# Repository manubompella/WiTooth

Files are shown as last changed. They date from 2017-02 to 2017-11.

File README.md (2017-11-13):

# WiTooth

The WiTooth is based on Espressif ESP32 WiFi-BT-BLE SoC (System on Chip), ESP32 contains two low-power Xtensa® 32-bit LX6 microprocessors running at 80 MHz. Features include:

 * Integrated 802.11 BGN WiFi transceiver
 * Integrated dual-mode Bluetooth (classic and BLE)
 * Dual-core Tensilica LX6 microprocessor
 * Up to 240MHz clock frequency
 * 520kB internal SRAM
 * 10-electrode capacitive touch support
 * Hardware accelerated encryption (AES, SHA2, ECC, RSA-4096)
 * 2.2 to 3.6V operating range
 * 2.5 µA deep sleep current
 * 3 SPI, 2 I2C, 2 UART
 * 16 PWM outputs
 * 2 DAC
 * 2 I2S
 * 18 analog-to-digital converter (ADC) channels
 
## Platform Features

 * Compatible with Arduino IDE
 * USB powered
 * CP2102 USB-to-UART Bridge
 * Extended breadboard compatible headers
 * UART, SPI, I2C
 * On-board RESET
 
## Maintainers

The WiTooth is maintained by thingTronics Innovations.

Main contributor:
 * Manohar Bompella@<manohar.bompella@thingtronics.com>
 * Poornima Nagesh @<poornima.nagesh@thingtronics.com>
 * Lovelesh Patel @<lovelesh.patel@thingtronics.com>

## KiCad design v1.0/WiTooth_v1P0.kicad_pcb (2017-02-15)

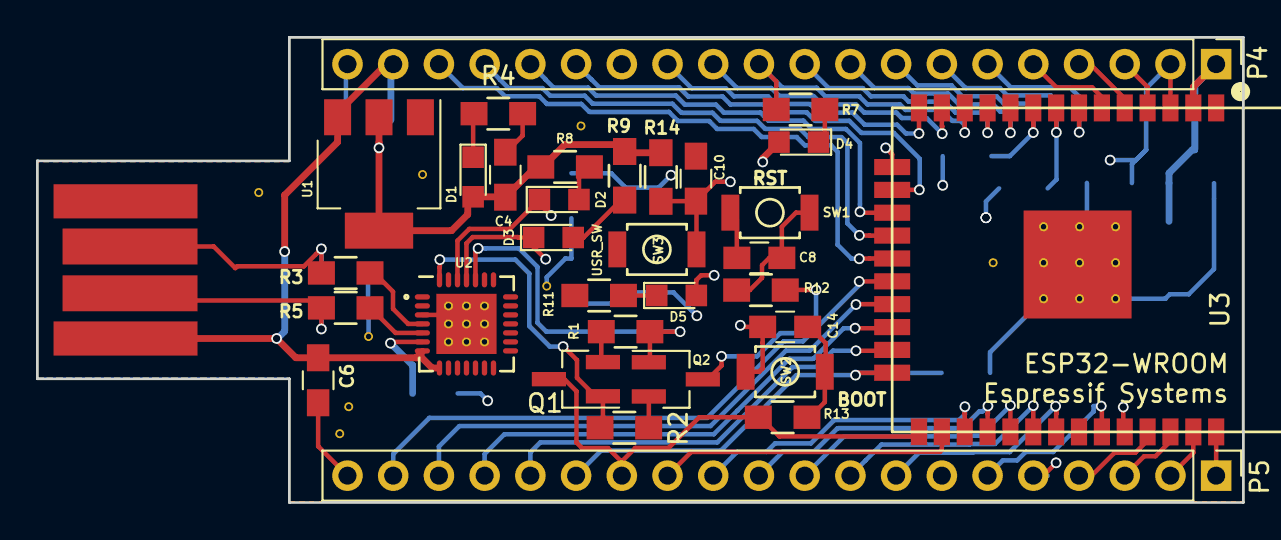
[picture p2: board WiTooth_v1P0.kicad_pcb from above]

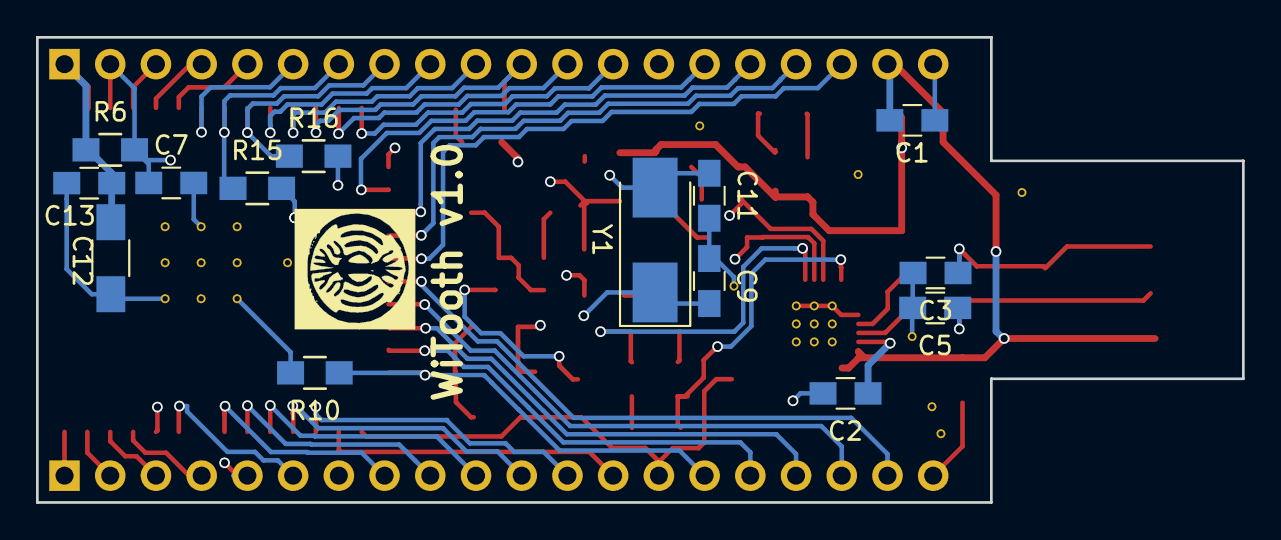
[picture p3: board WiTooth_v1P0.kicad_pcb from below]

Board: 4 copper layers, 67.0 x 25.8 mm, 47 parts (14 on the bottom side), 54 nets.

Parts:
C1, C4: 10uF; C_0805_HandSoldering
C2: 0.1uF; C_0805_HandSoldering
C3, C5: 47pF; C_0805_HandSoldering
C6, C13: 1uF; C_0805_HandSoldering
C7, C8, C10, C14: 1nF; C_0805_HandSoldering
C9, C11: 27pF; C_0805_HandSoldering
C12: 100uF; C_1206_HandSoldering
D1: PWR_GREEN; LED_0805
D2, D3: YELLOW; LED_0805
D4: CONN_LED; LED_0805
D5: USER_LED; LED_0805
P1: USB_A_MALE; usb-PCB_male
P4, P5: CONN_01X20; Pin_Header_Straight_1x20_Pitch2.54mm
Q1, Q2: Q_NPN_EBC; SOT-23_Handsoldering
R1, R2, R6: 12K; R_0805_HandSoldering
R3, R5: 27E; R_0805_HandSoldering
R4: 1K; R_0805_HandSoldering
R7, R11, R12, R13, R14: 470E; R_0805_HandSoldering
R8, R9: R; R_0805_HandSoldering
R10: 5K; R_0805_HandSoldering
R15, R16: 0E; R_0805_HandSoldering
SW1: RESET; SW_SPST_B3U-1000P_SUNROM
SW2: BOOT; SW_SPST_B3U-1000P_SUNROM
SW3: USER_SW; SW_SPST_B3U-1000P_SUNROM
U1: AMS1117-3V3; SOT-223
U2: CP2102; QFN-28-1EP_5x5mm_Pitch0.5mm
U3: ESP-32_WROOM32_Rectangle; ESP32-WROOM_SMALLER_FOOTPRINT
Y1: Crystal; Crystal_SMD_0603-2pin_6.0x3.5mm_HandSoldering

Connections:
+3V3: C4.1, C12.1, C13.1, D1.2, D4.2, P4.1, R6.1, R8.1, R9.1, R14.1, U1.2, U1.4, U3.2
+5V: C1.1, C6.1, P1.1, P4.19, U1.3, U2.7, U2.8
CLK: P5.19, U3.20
CMD: P4.18, U3.19
DTR: Q1.1, R2.2, U2.28
EN: C7.1, P4.2, Q2.3, R6.2, R12.1, U3.3
GND: C1.2, C2.2, C3.2, C4.2, C5.2, C6.2, C7.2, C8.2, C9.2, C10.2, C11.2, C12.2, C13.2, C14.2, P1.4, P4.14, P4.20, P5.1, P5.7, P5.20, R4.2, R10.2, R11.2, SW1.1, SW2.1, SW3.1, U1.1, U2.3, U2.29, U3.1, U3.15, U3.38, U3.39
IO0: P5.14, Q1.3, R13.1, U3.25
IO2: P5.15, R10.1, U3.24
IO4: P5.13, U3.26
IO5: P5.10, U3.29
IO12: P4.13, U3.14
IO13: P4.15, U3.16
IO14: P4.12, U3.13
IO15: P5.16, U3.23
IO16: P5.12, U3.27
IO17: P5.11, U3.28
IO18: P5.9, U3.30
IO19: P5.8, U3.31
IO21: P5.6, U3.33
IO22: P5.3, U3.36
IO23: P5.2, U3.37
IO25: P4.9, U3.10
IO26: P4.10, U3.11
IO27: P4.11, R7.2, U3.12
IO32: P4.7, R15.1, U3.8
IO33: P4.8, R16.1, U3.9
IO34: C10.1, P4.5, R14.2, SW3.2, U3.6
IO35: D5.2, P4.6, U3.7
unnamed: C3.1, P1.3, R3.2
unnamed: C5.1, P1.2, R5.2
unnamed: C8.1, R12.2, SW1.2
unnamed: C9.1, R15.2, Y1.1
unnamed: C11.1, R16.2, Y1.2
unnamed: C14.1, R13.2, SW2.2
unnamed: D1.1, R4.1
unnamed: D2.2, R8.2
unnamed: D3.2, R9.2
unnamed: D4.1, R7.1
unnamed: D5.1, R11.1
unnamed: Q1.2, R1.1
unnamed: Q2.2, R2.1
unnamed: R3.1, U2.4
unnamed: R5.1, U2.5
RTS: Q2.1, R1.2, U2.24
RXD0: D2.1, P5.5, U2.26, U3.34
SD0: P5.18, U3.21
SD1: P5.17, U3.22
SD2: P4.16, U3.17
SD3: P4.17, U3.18
SENSOR_VN: P4.4, U3.5
SENSOR_VP: P4.3, U3.4
TXD0: D3.1, P5.4, U2.25, U3.35
VDD: C2.1, U2.6

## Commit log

2016-12-12 Added Schematic , foot prints and layout
    [Esp8266+HM-10.kicad_pcb, Esp8266+HM-10.sch]
2016-12-14 Schematic and layout changed
    - Schematic
    i removed 2x4 header and added 1x5 ,1x4 header
    - layout changed
    [Esp8266+HM-10.kicad_pcb, Esp8266+HM-10.sch]
2017-02-05 Schematic and Reference files Added
    Schematic ,
    Reference files Added
    [Esp8266+HM-10.kicad_pcb, Esp8266+HM-10.sch, WiTooth.kicad_pcb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]
2017-02-05 updated schematic
    - added cp2102
    - added come extra redundancy
    [WiTooth.kicad_pcb, WiTooth.sch, WiTooth_v1P0.kicad_pcb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]
2017-02-08 schematic half verified; footprint association done
    [WiTooth_v1P0.sch]
2017-02-08 all changes done; schematic verified
    [WiTooth_v1P0.sch]
2017-02-08 initial placement started
    [WiTooth_v1P0.kicad_pcb, WiTooth_v1P0.sch]
2017-02-09 basic placement done
    [WiTooth_v1P0.kicad_pcb, WiTooth_v1P0.sch]
2017-02-12 schematic updated and some parts removed; layout work started
    [WiTooth_v1P0.kicad_pcb, WiTooth_v1P0.sch]
2017-02-15 Routing completed for all
    Routing completed for all
    [WiTooth_v1P0.kicad_pcb]
